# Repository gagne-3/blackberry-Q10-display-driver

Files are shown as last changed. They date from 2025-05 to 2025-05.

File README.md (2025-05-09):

# BlackBerry Q10 Display Assembly Driver

This repo contains the schematics and code for a display driver meant to provide compatibility with the BlackBerry Q10 display and touch screen.
> [!CAUTION]
> Heavy work in progress, project is to be considered non-functional and incomplete.

## Background Information

This project intends to provide a way to use a Q10 display assembly with a Raspberry Pi 4, but can be adapted to work with any computer that supports MIPI DSI.

The specific panel included in the Q10 display assembly, AMS309PW01, was specially made for the BlackBerry Q10 by Samsung SMD.  This display is a 3.1" AMOLED display with a resolution of 720x720. It communicates to the device using MIPI. Touch inputs are handled by an [Atmel mXT224S](https://www.microchip.com/en-us/product/atmxt224s#Documentation) connected to the built in digitizer.

## The Story

Initially, I fell down a rabbit hole and ended up looking into the wrong panel for this project. If you search for 3.1" 720x720 displays, the only readily available one is the LT031MDZ4000. These panels can be found readily on Aliexpress and Alibaba with MIPI driver boards. Others have also worked on creating custom drivers for this panel, notably [Jamwu](https://github.com/jamwu/RPI-LCD-LT031MDZ4000) and [Will-TM](https://github.com/will-tm/RPI-LCD-LT031MDZ4000).

Unfortunately, once I got my hands on a Q10 display module, I realized that it does not have a LT031MDZ4000 panel. Despite being the same size and resolution, the LT031MDZ4000 is an LCD panel that was made for the BlackBerry Q5, not the Q10. Upon tearing apart my Q10 display, I found the real panel model, AMS309PW01. Unfortunately for me, the AMS309PW01 is practically impossible to find information about. Only very basic information can be found on places such as [Panelook](https://www.panelook.com/AMS309PW01-0_Samsung_3.1_OLED_overview_21542.html). There do not appear to be any resellers of this panel, and there are no schematics or notes about how these panels work.

This caused me to lose hope on this project. Without a schematic, it was nearly impossible to create a driver board to make this display functional. I was considering going in with a multimeter and painstakingly reverse engineering the electronics attached to the display assembly. Thankfully, I caught a lucky break. While searching for schematics, I decided to search for general BlackBerry Q10 Schematics. That's when I fell upon a random blog that had a bunch of PDFs uploaded to it. These PDFs contained schematics for the entire mainboard of the Q10, which was exactly what I needed.

I will not link to the blog in question since it appeared to be a reupload. The PDFs are watermarked with a URL to what seems to be a dead website. a copy of the schematic can be found [here](schematics/sch-44860-106_rev1.pdf).

# Technical Details

## Q10 Display Connector Pinout

The display connector on the Q10 display assembly is a `Hirose BM14B(0.8)-30DP-0.4V`, which means that the driver board requires a `Hirose BM14B(0.8)-30DS-0.4V` socket to connect.

Below is a pinout of the Q10 motherboard display connector socket compiled from information present on Page 28 of the schematic.

| Pin | Signal Name | Description |
| --- | --- | --- |
| MP1 | GND | Ground |
| MP2 | GND | Ground |
| 1 | VSYS_F | Main system power |
| 2 | V2_85TSP_F | Touchscreen AVDD (2.85V) |
| 3 | VSYS_F | Main system power |
| 4 | V1_8TSP_F | Touchscreen VDD (1.8V) |
| 5 | GND | Ground |
| 6 | GND | Ground |
| 7 | — | Not Connected |
| 8 | I2C_SCL_TS | Touchscreen I²C Clock |
| 9 | GND | Ground |
| 10 | I2C_SDA_TS | Touchscreen I²C Data |
| 11 | OLED_MIPI:D1_P | MIPI DSI Data Lane 1+ |
| 12 | GND | Ground |
| 13 | OLED_MIPI:D1_N | MIPI DSI Data Lane 1− |
| 14 | TSCRN_INT_N | Touchscreen Interrupt |
| 15 | GND | Ground |
| 16 | TSCRN_RST_N | Touchscreen Reset |
| 17 | OLED_MIPI:CLK_P | MIPI DSI Clock+ |
| 18 | GND | Ground |
| 19 | OLED_MIPI:CLK_N | MIPI DSI Clock− |
| 20 | V3_10LED_F | Display power (3.1V) |
| 21 | GND | Ground |
| 22 | V3_10LED_F | Display power (3.1V) |
| 23 | OLED_MIPI:D0_P | MIPI DSI Data Lane 0+ |
| 24 | GND | Ground |
| 25 | OLED_MIPI:D0_N | MIPI DSI Data Lane 0− |
| 26 | V2_20LED_F | Display secondary power (2.2V) |
| 27 | GND | Ground |
| 28 | V2_20LED_F | Display secondary power (2.2V) |
| 29 | OLED_RST_N | Display Reset |
| 30 | GND | Ground |
| MP3 | GND | Ground |
| MP4 | GND | Ground |

Note: the pinout from Hirose is different to how the Blackberry schematic labels the pins. The official pinout from the manufacturer has the edge pins labeled as "MP#" while the Blackberry schematic includes them in the pin count. These edge pins are all grounds anyway, so I have included the official manufacturer pinout to match to the schematic.

## Raspberry Pi Display Connector Pinout

The display connector on the Raspberry Pi 4b is a 15 pin 1mm pitch FFC connector, specifically `SFW15R-2STE1LF`.

The following pinout of the Raspberry Pi 4b display connector is compiled from information from the [official Raspberry Pi 4b Schematic.](https://datasheets.raspberrypi.com/rpi4/raspberry-pi-4-reduced-schematics.pdf)

| Pin | Signal Name | Description |
| --- | --- | --- |
| 1 | GND | Ground |
| 2 | DSI1_DN1 | MIPI DSI Data Lane 1- |
| 3 | DSI1_DP1 | MIPI DSI Data Lane 1+ |
| 4 | GND | Ground |
| 5 | DSI1_CN | MIPI DSI Clock- |
| 6 | DSI1_CP | MIPI DSI Clock+ |
| 7 | GND | Ground |
| 8 | DSI1_DN0 | MIPI DSI Data Lane 0- |
| 9 | DSI1_DP0 | MIPI DSI Data Lane 0+ |
| 10 | GND | Ground |
| 11 | SCL0 | Touchscreen I²C Clock |
| 12 | SDA0 | Touchscreen I²C Data |
| 13 | GND | Ground |
| 14 | 3V3 | Display power (3.3V) |
| 15 | 3V3 | Display power (3.3V) |

## Display Panel Controller IC

Based on some basic googling and ChatGPT-ing, I believe the most likely controller IC for this panel is the Samsung S6E63M0. This IC is used in other Super AMOLED smartphone display panels of the time period and features the same integrated touchscreen architecture as is present on the Q10 display assembly.

Drivers for this controller IC already exist within the [Linux Kernel](https://github.com/torvalds/linux/blob/master/drivers/gpu/drm/panel/panel-samsung-s6e63m0-dsi.c)

## Power Supply Electronics

The Q10 display assembly requires four different voltages: 1.8, 2.2, 2.85, and 3.1 volts. The Raspberry Pi 4b display connector supplies 3.3 volts. We can provide these voltages by using LDO regulators. 1.8 volts is common for regulators, however adjustable regulators will be needed for the 2.2, 2.85, and 3.1 volt supplies. Below is a table detailing the necessary ICs for the driver board:

| Voltage | Part Number |
| --- | --- |
| 1.8v | TLV75718PDRVR |
| 2.2v | TLV75901PDRVR |
| 2.85v | TLV75901PDRVR |
| 3.1v | TLV75901PDRVR |

### Adjustable Voltage Resistance Values

In order to adjust the output voltage of the TLV759 LDOs, two resistors need to be connected, the ratio of which determines the output voltage. Below are the necessary resistance values for the LDOs:

| Voltage | R1 | R2 |
| --- | -- | -- |
| 2.2v | 30k | 10k |
| 2.85v | 38.3k | 9.09k |
| 3.1v | 42.2k | 9.09k |

## Logic Level Shifting

For the touchscreen reset and interrupt pins, we need to use a logic level shifter in order to be able to connect these to the GPIO of the raspberry pi. To do this, we can use a `TXB0102`.

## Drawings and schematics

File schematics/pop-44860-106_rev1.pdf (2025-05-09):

U3300

| REVISIONS

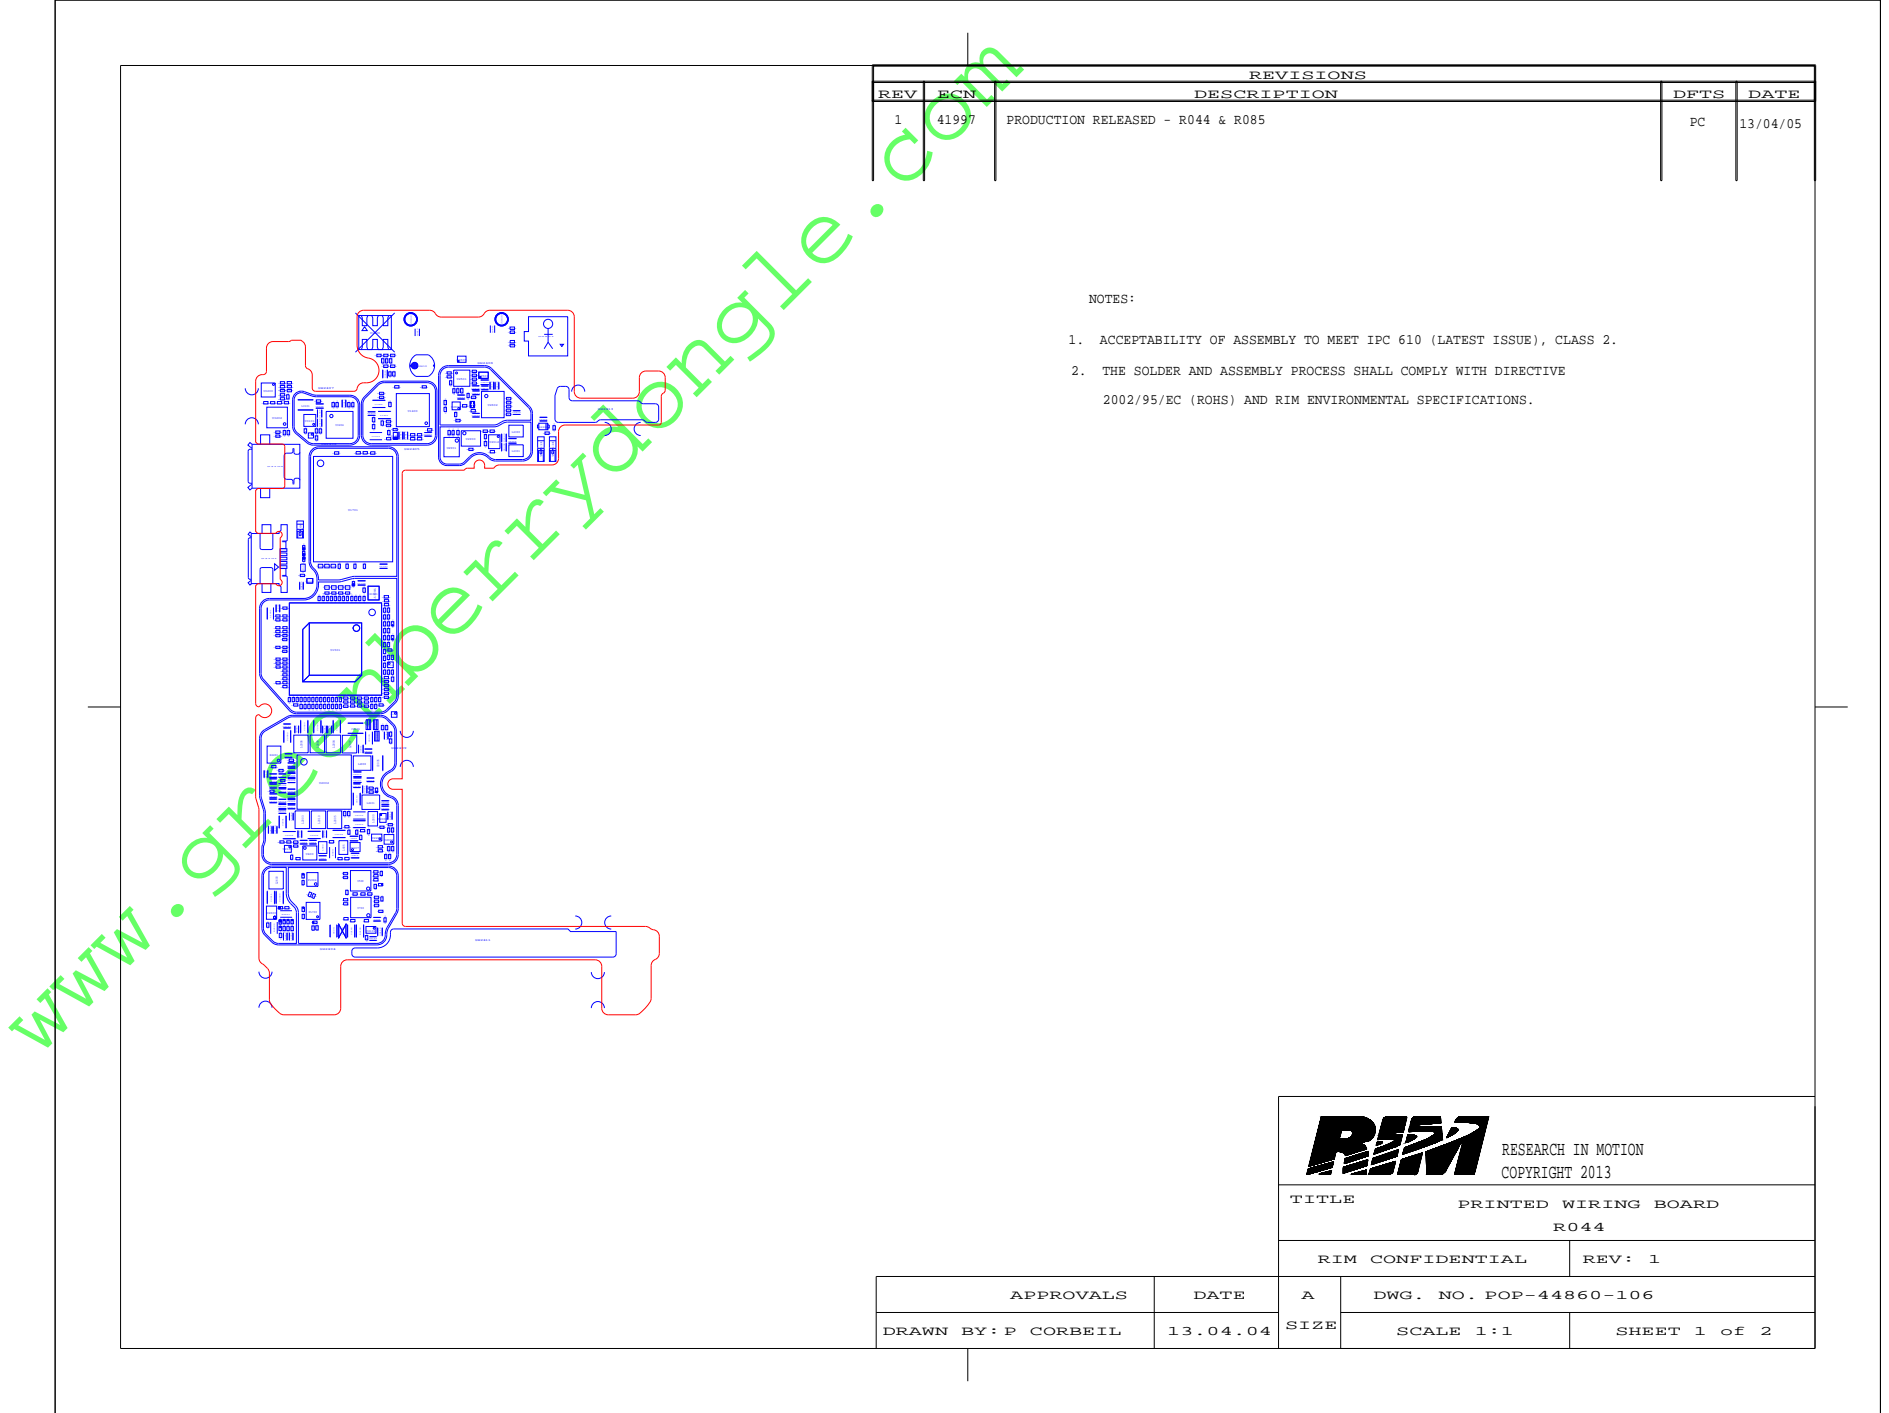
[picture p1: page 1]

REV | ECN | DESCRIPTION | DFTS | DATE

1. ACCEPTABILITY OF ASSEMBLY TO MEET IPC 610 (LATEST ISSUE), CLASS 2.

2. THE SOLDER AND ASSEMBLY PROCESS SHALL COMPLY WITH DIRECTIVE

2002/95/EC (ROHS) AND RIM ENVIRONMENTAL SPECIFICATIONS.

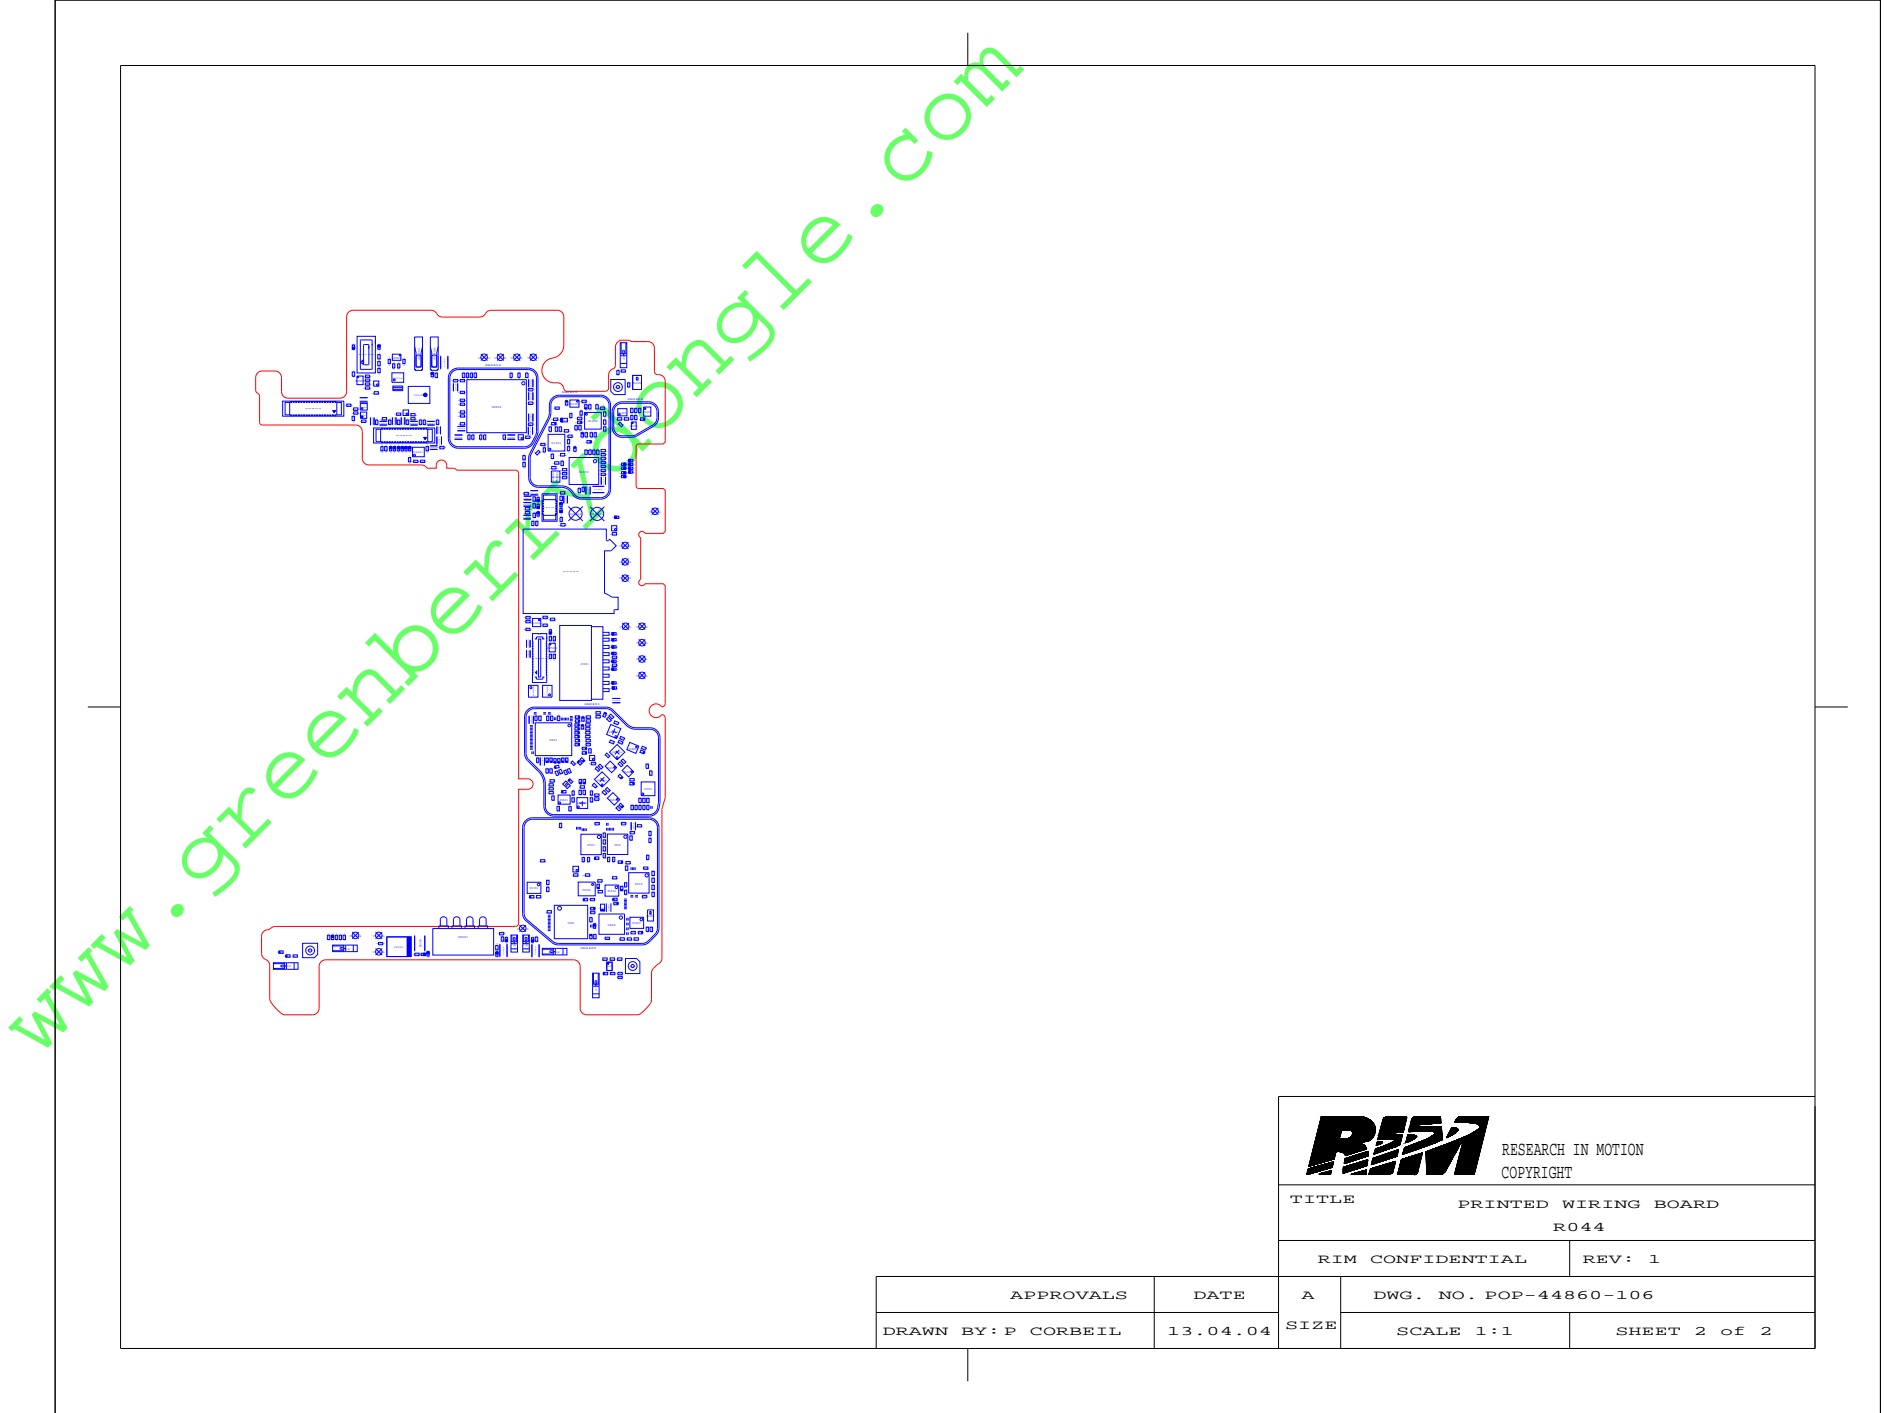
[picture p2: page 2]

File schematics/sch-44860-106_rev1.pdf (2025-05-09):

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

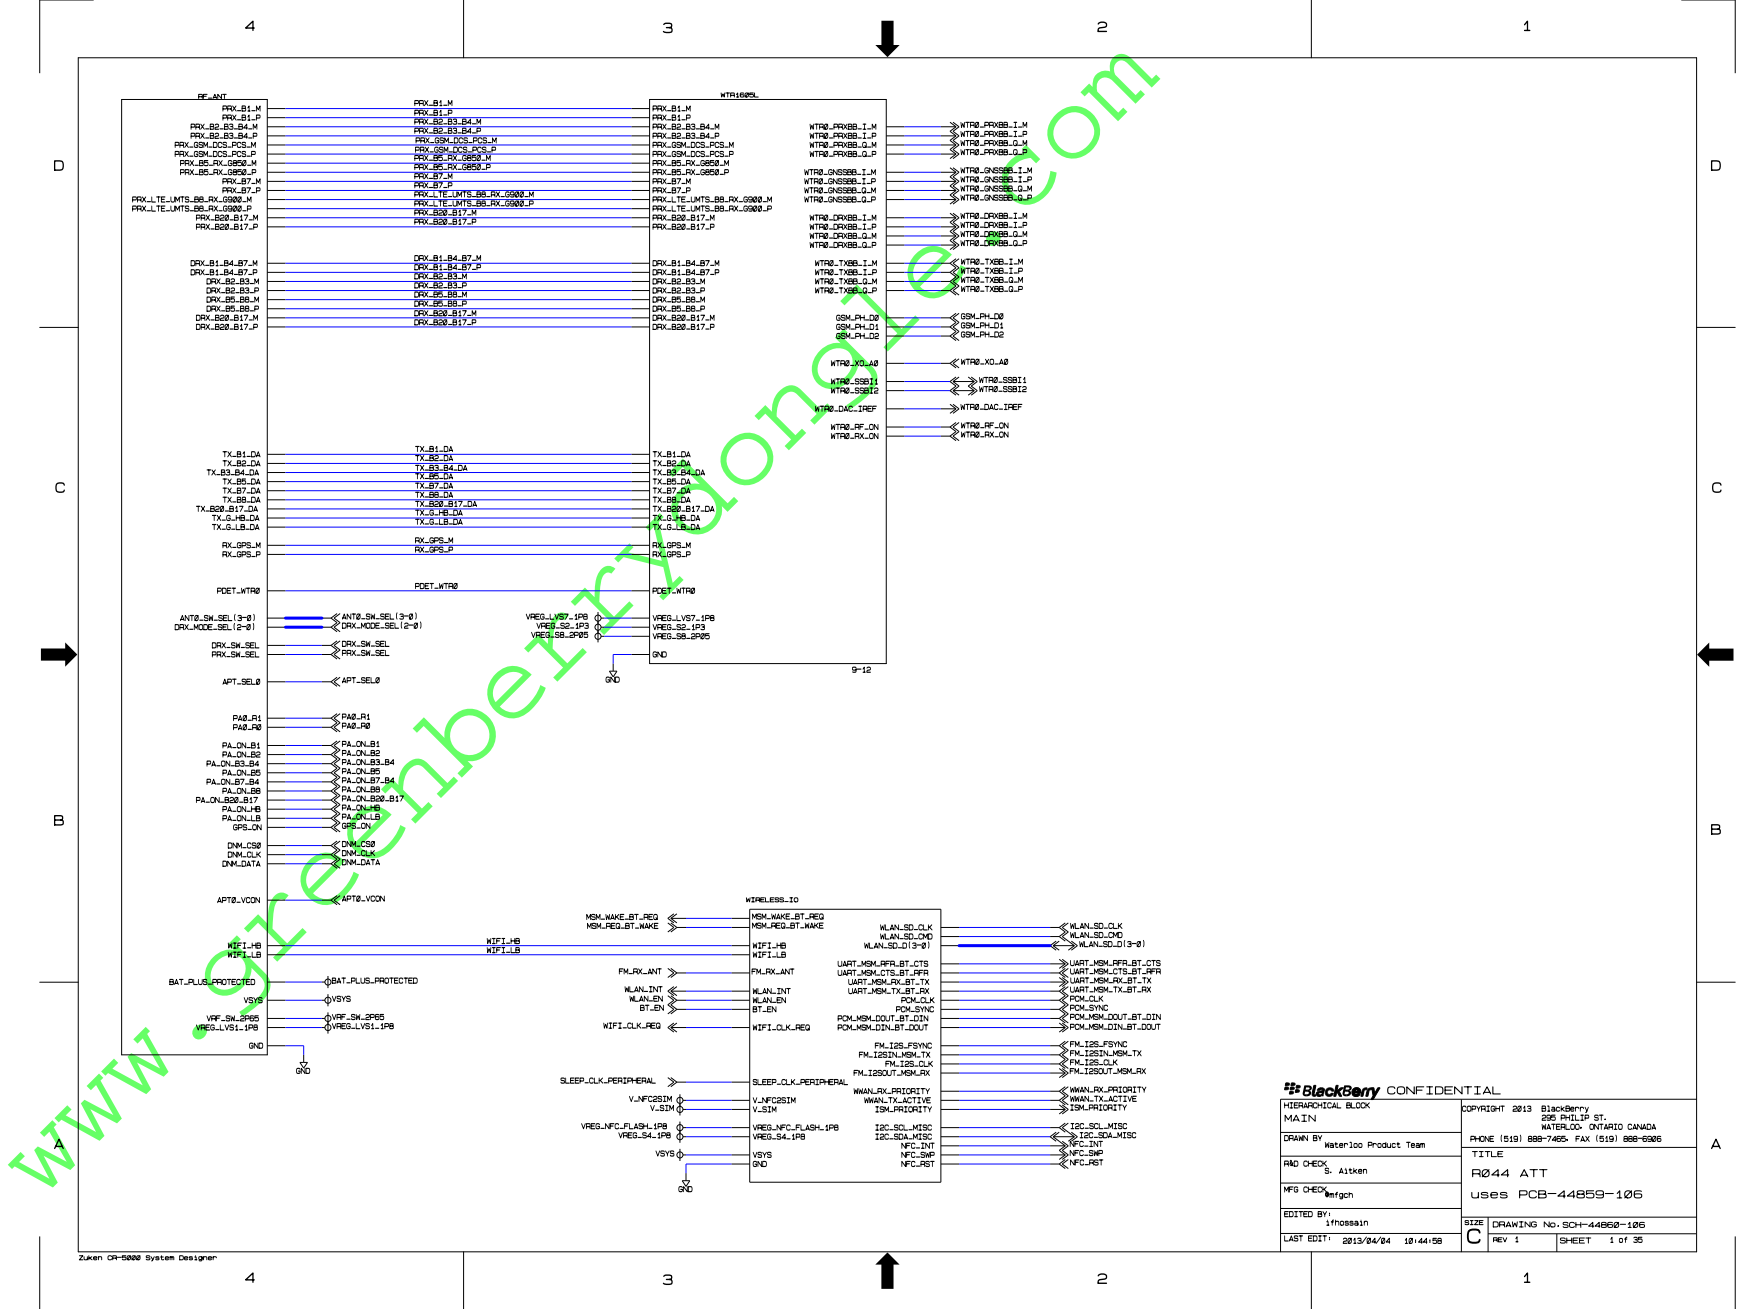
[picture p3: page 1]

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

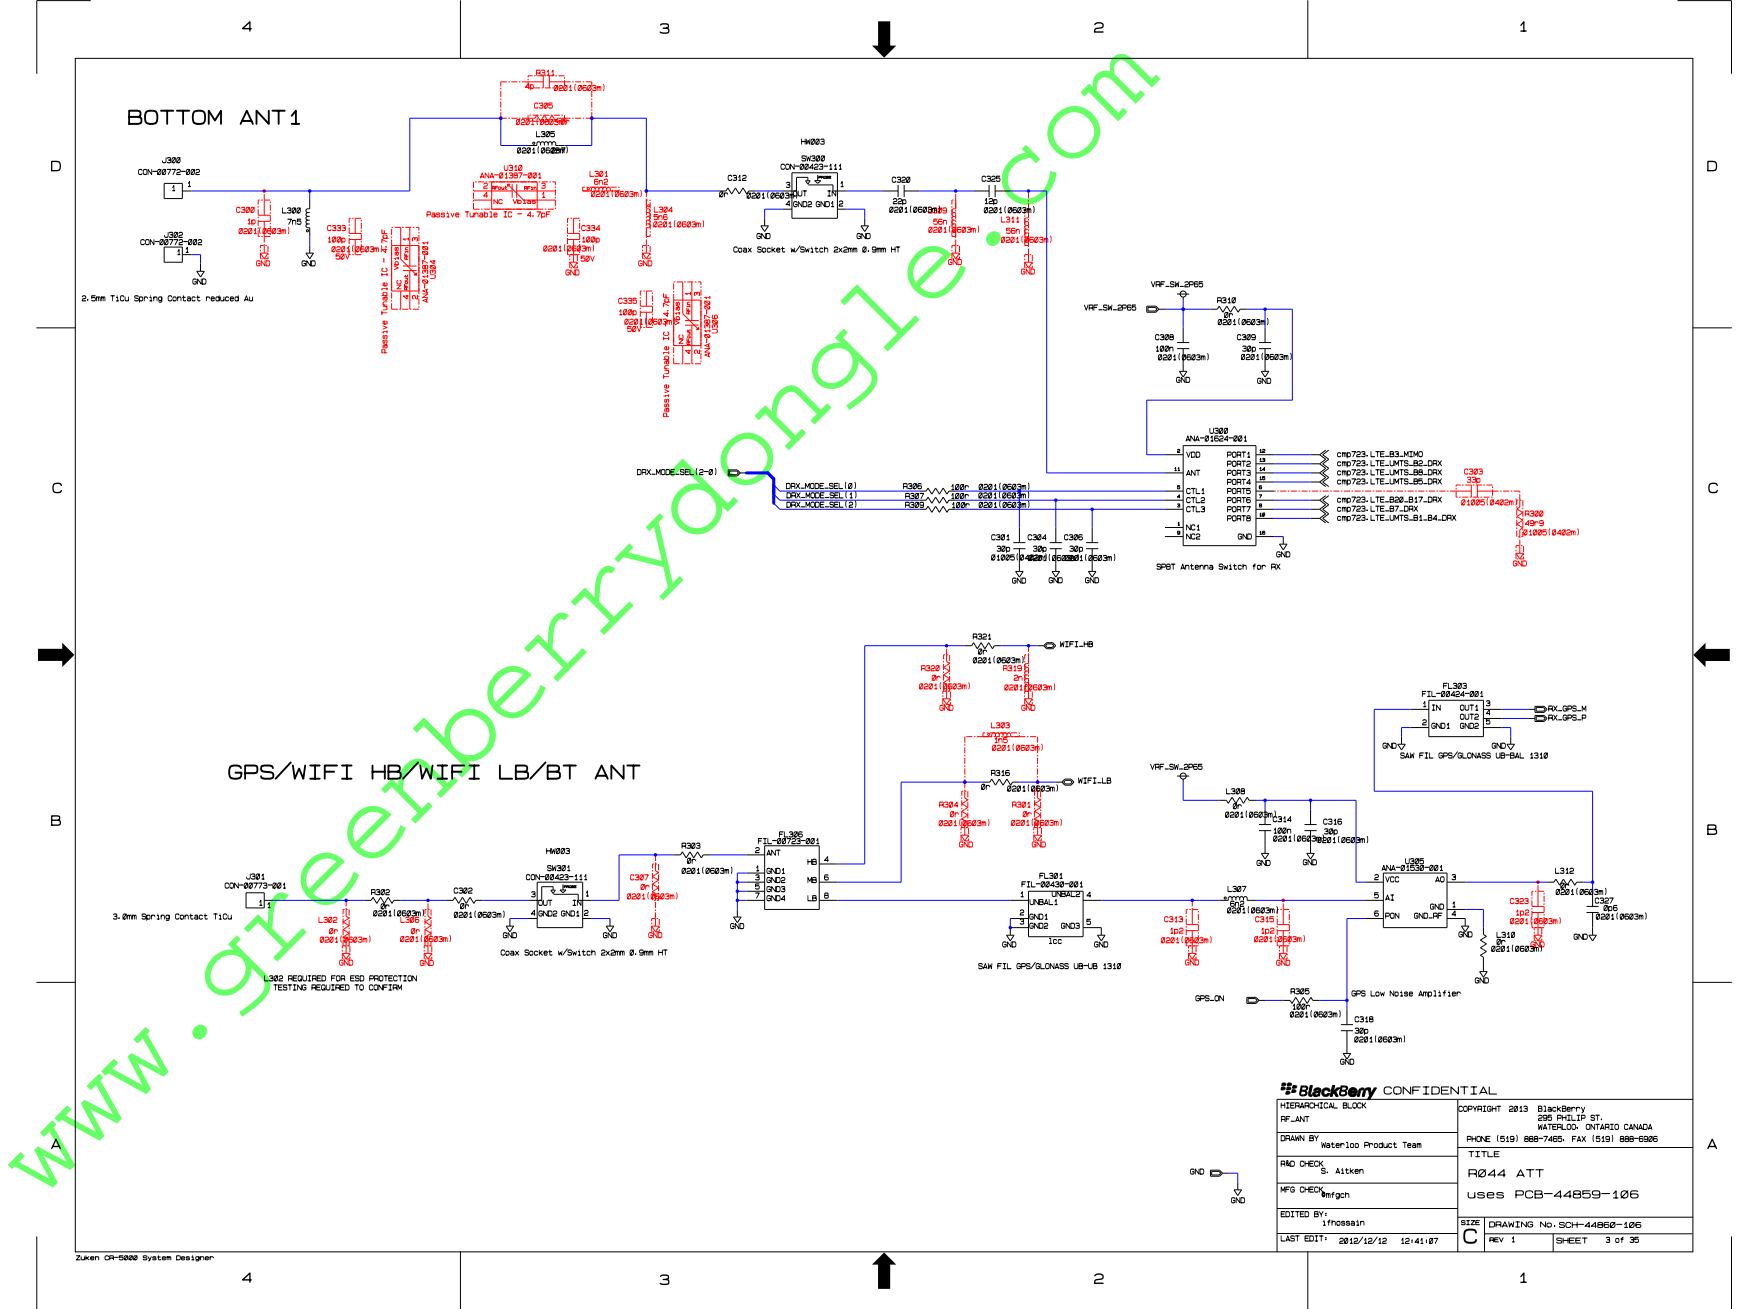
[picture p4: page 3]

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

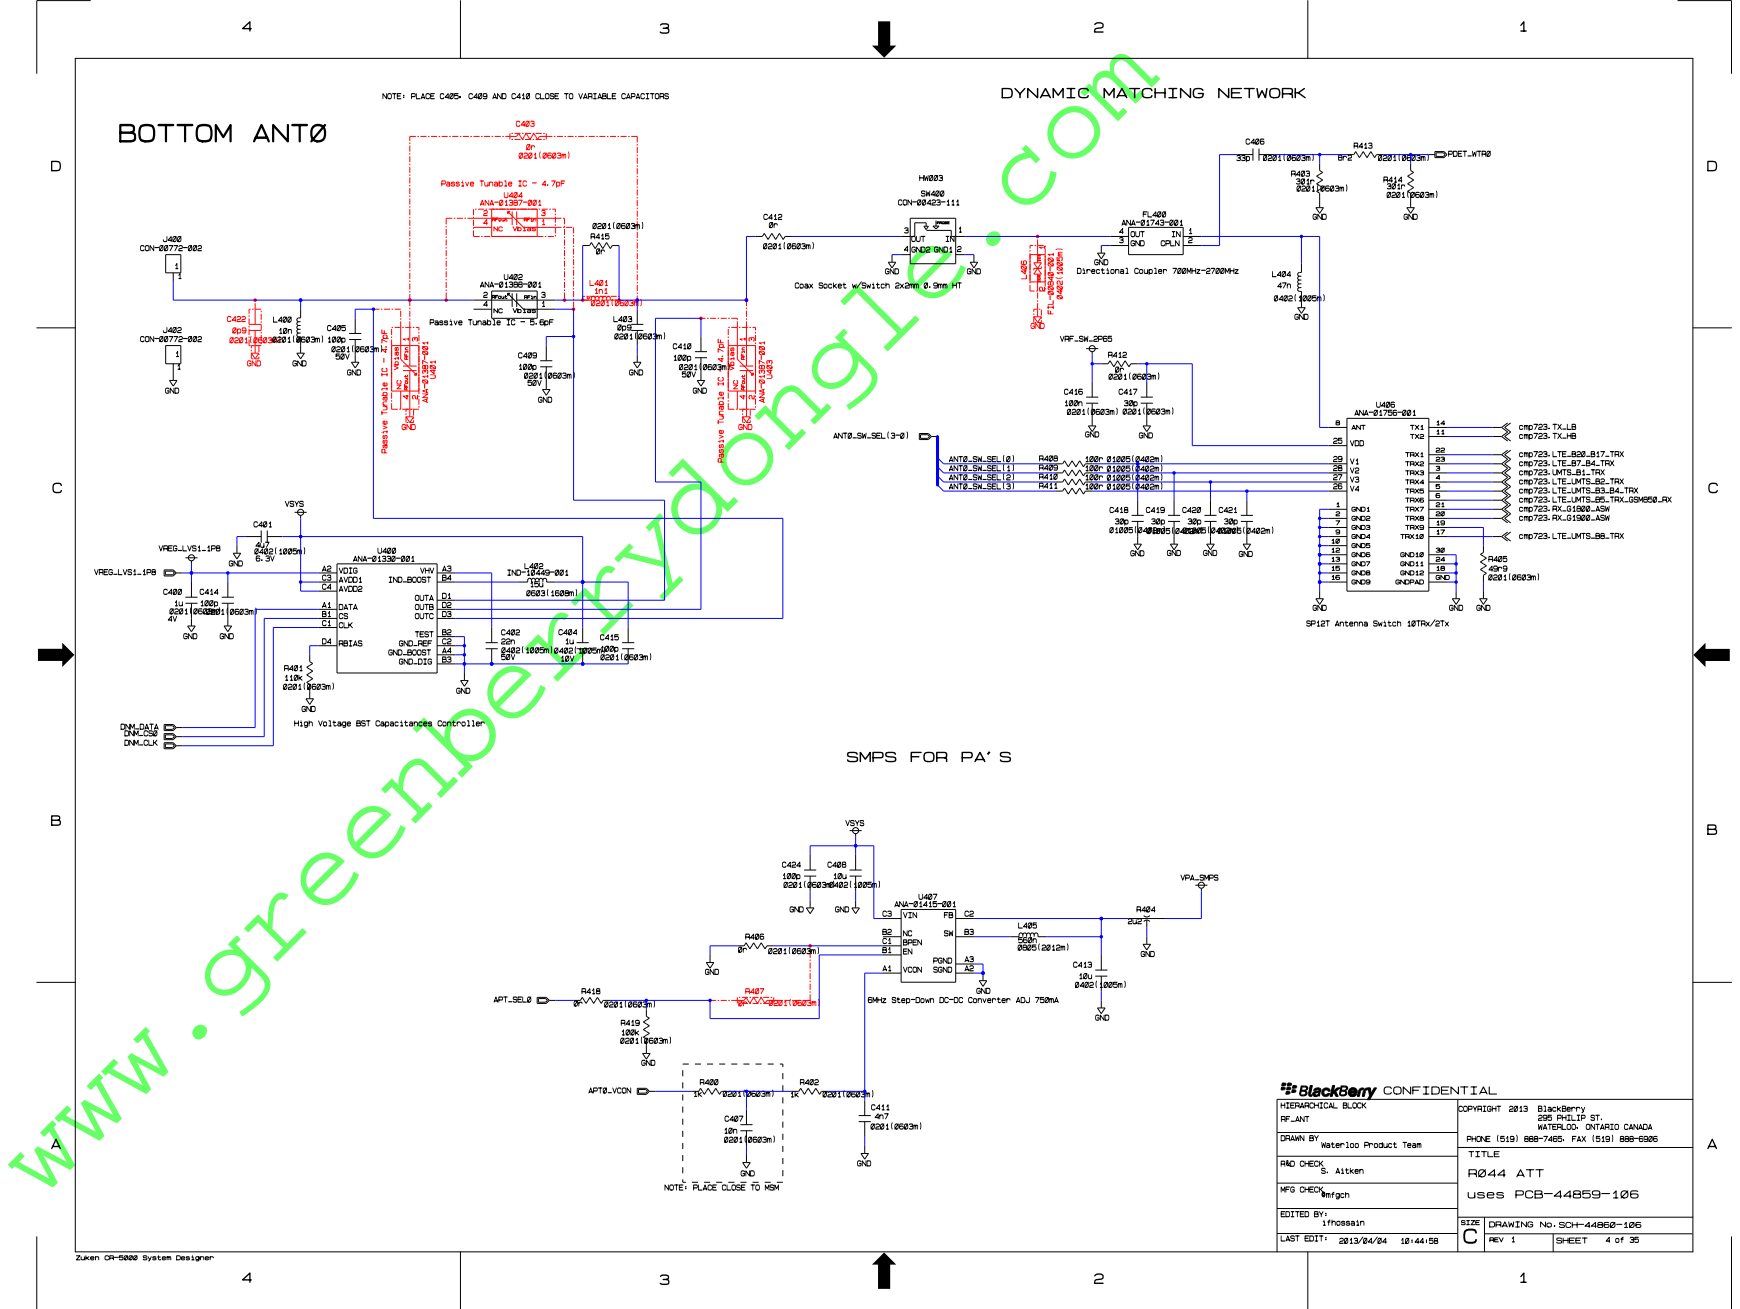
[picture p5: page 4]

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

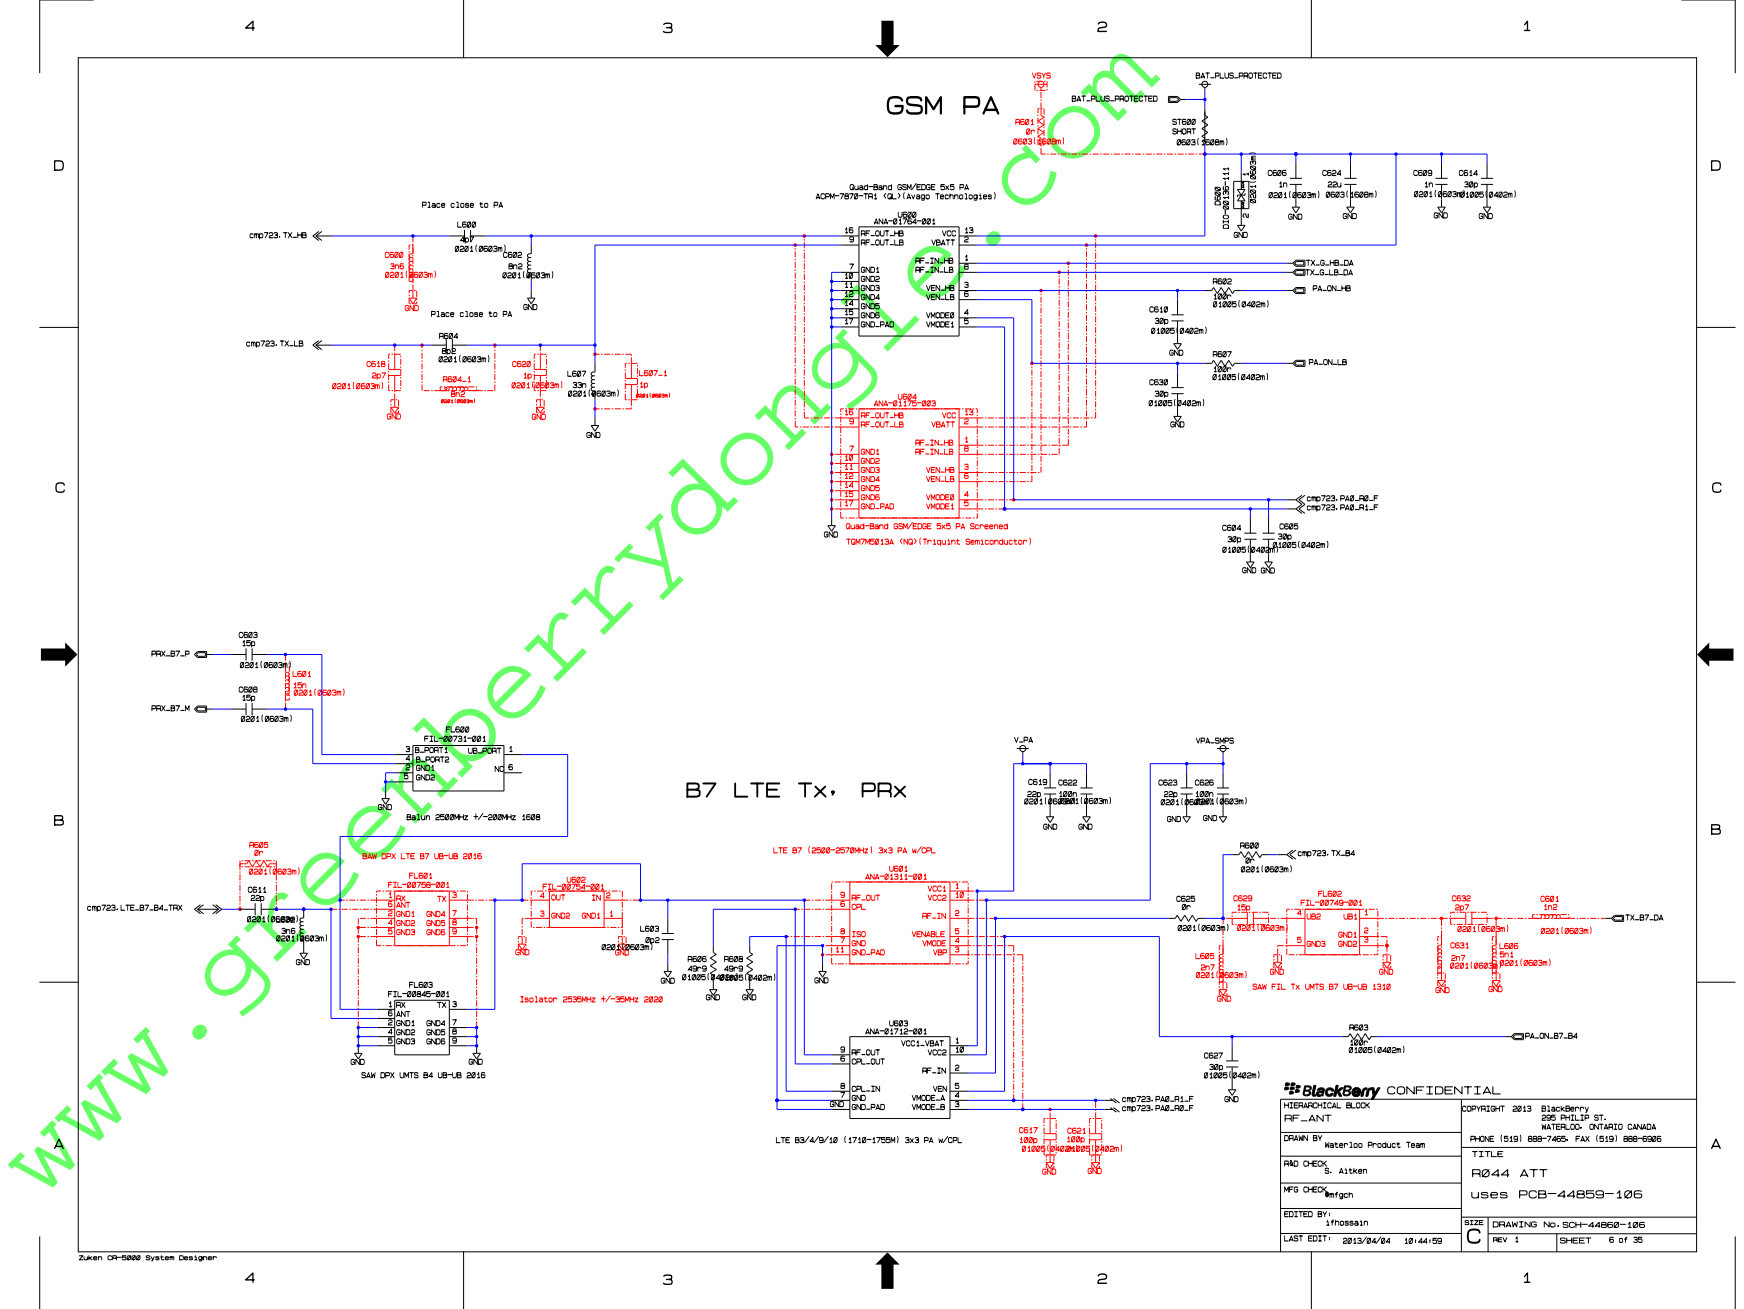
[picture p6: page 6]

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

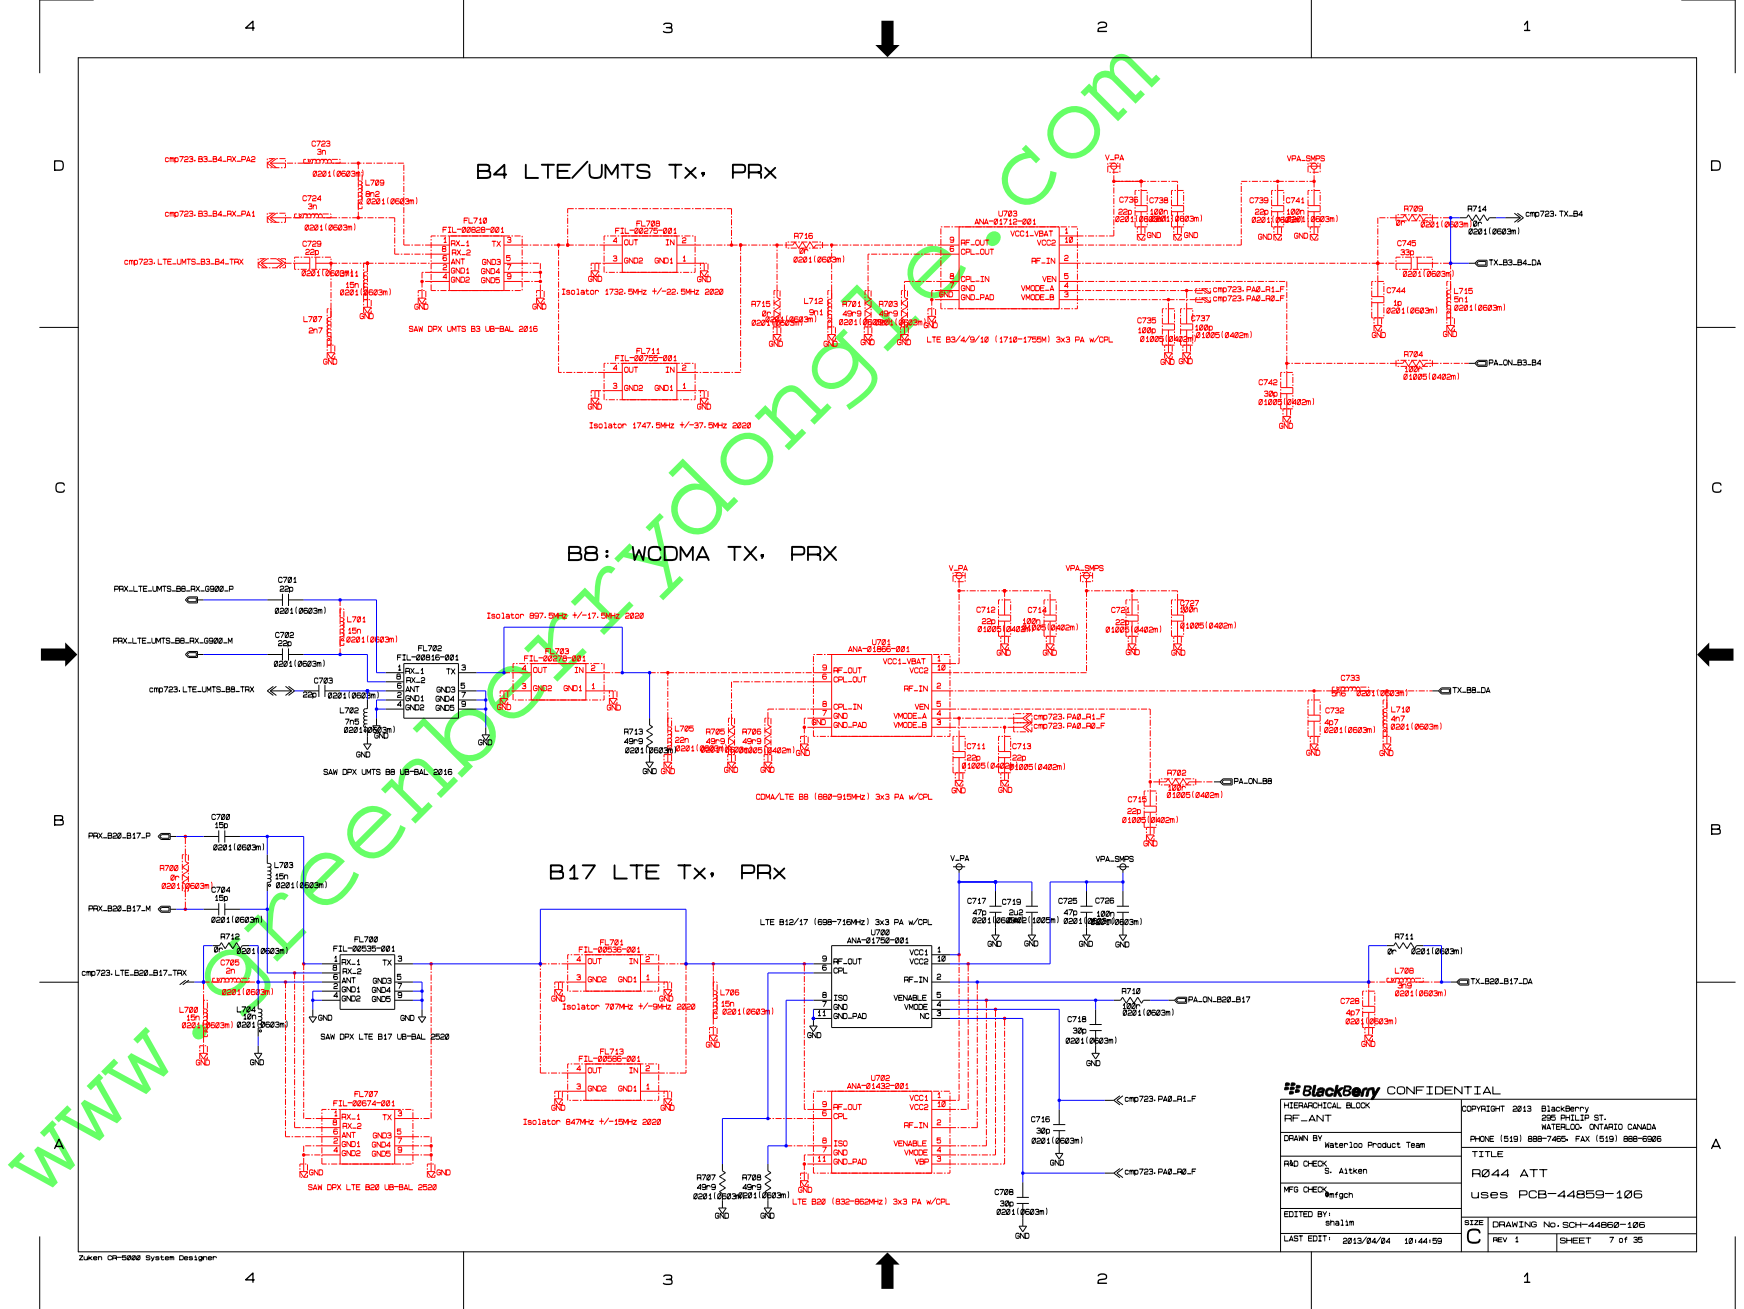
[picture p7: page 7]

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

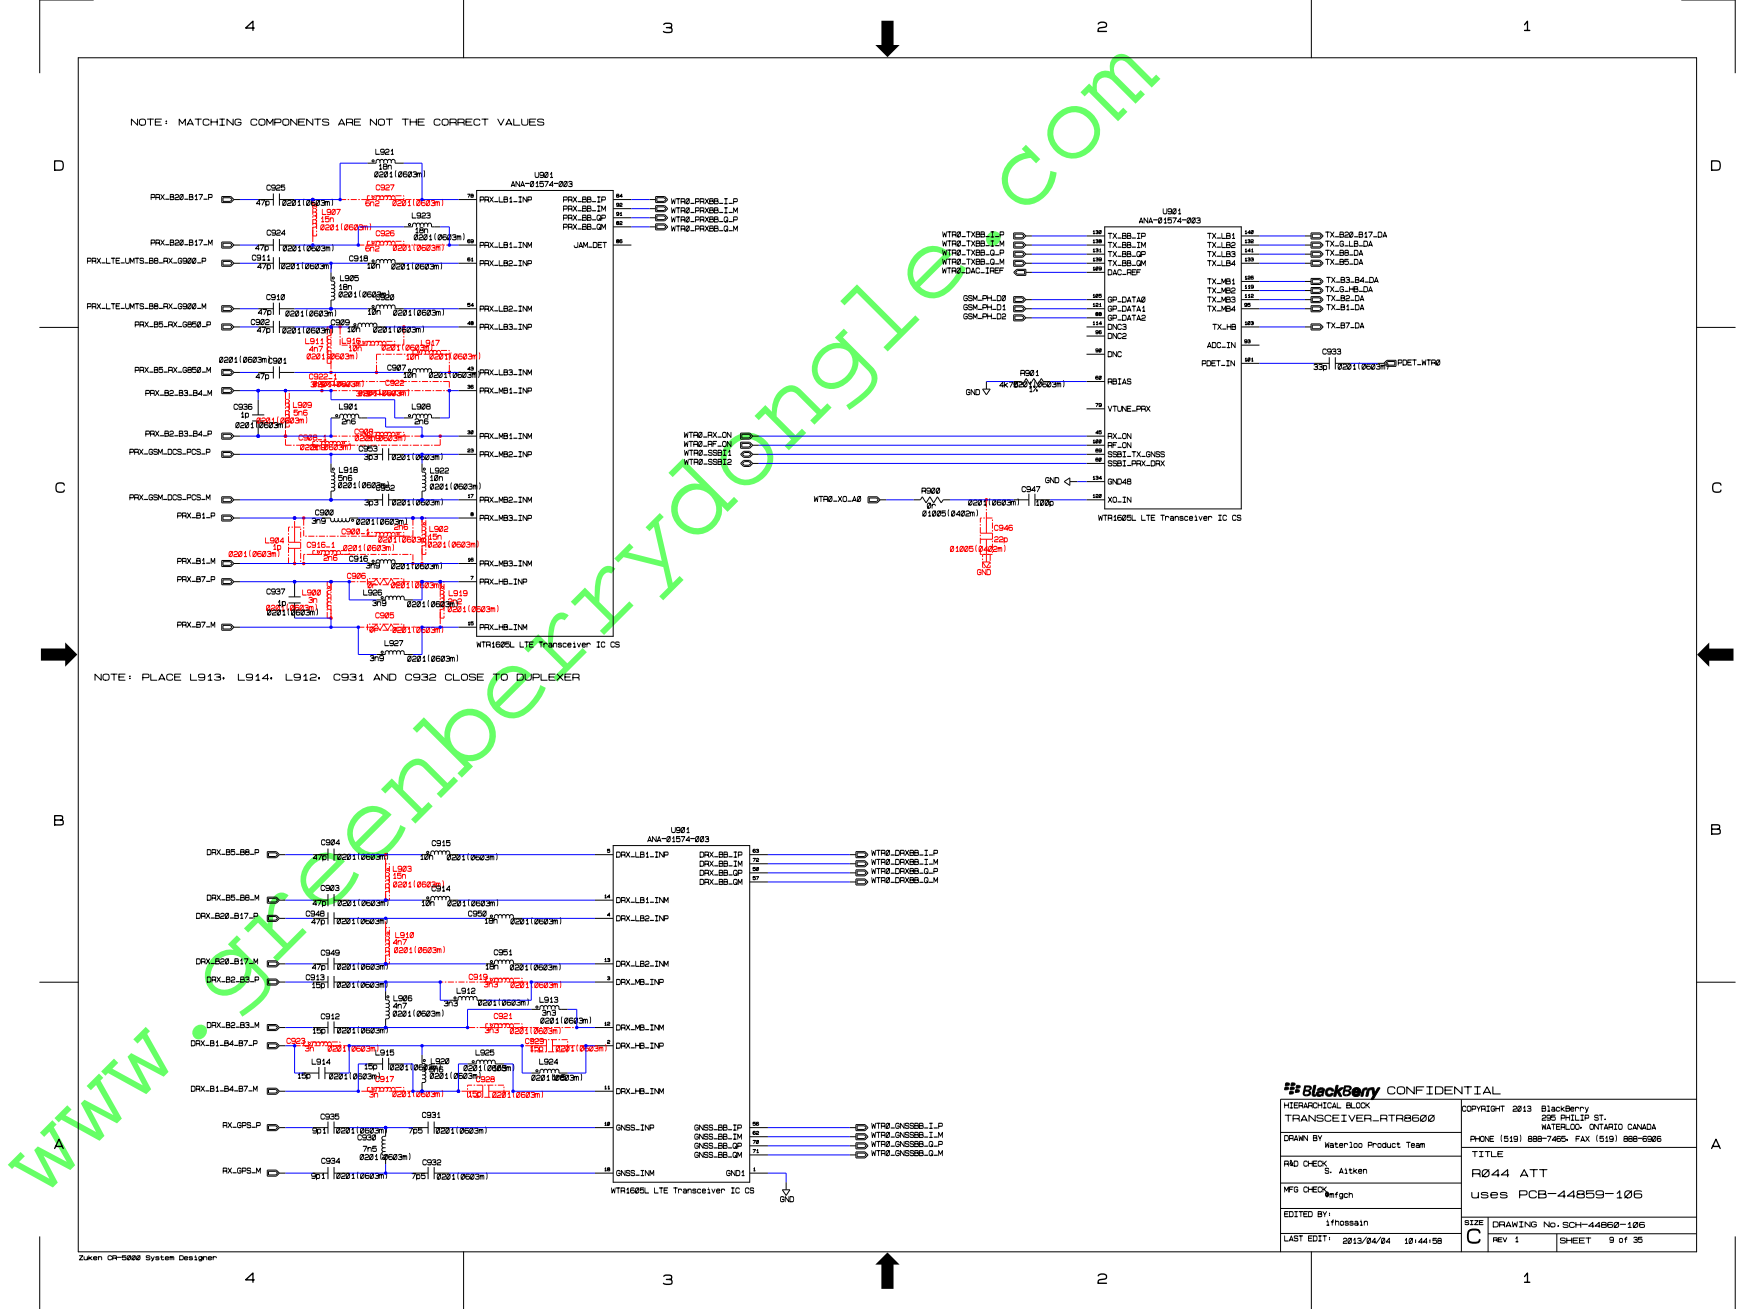
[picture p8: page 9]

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

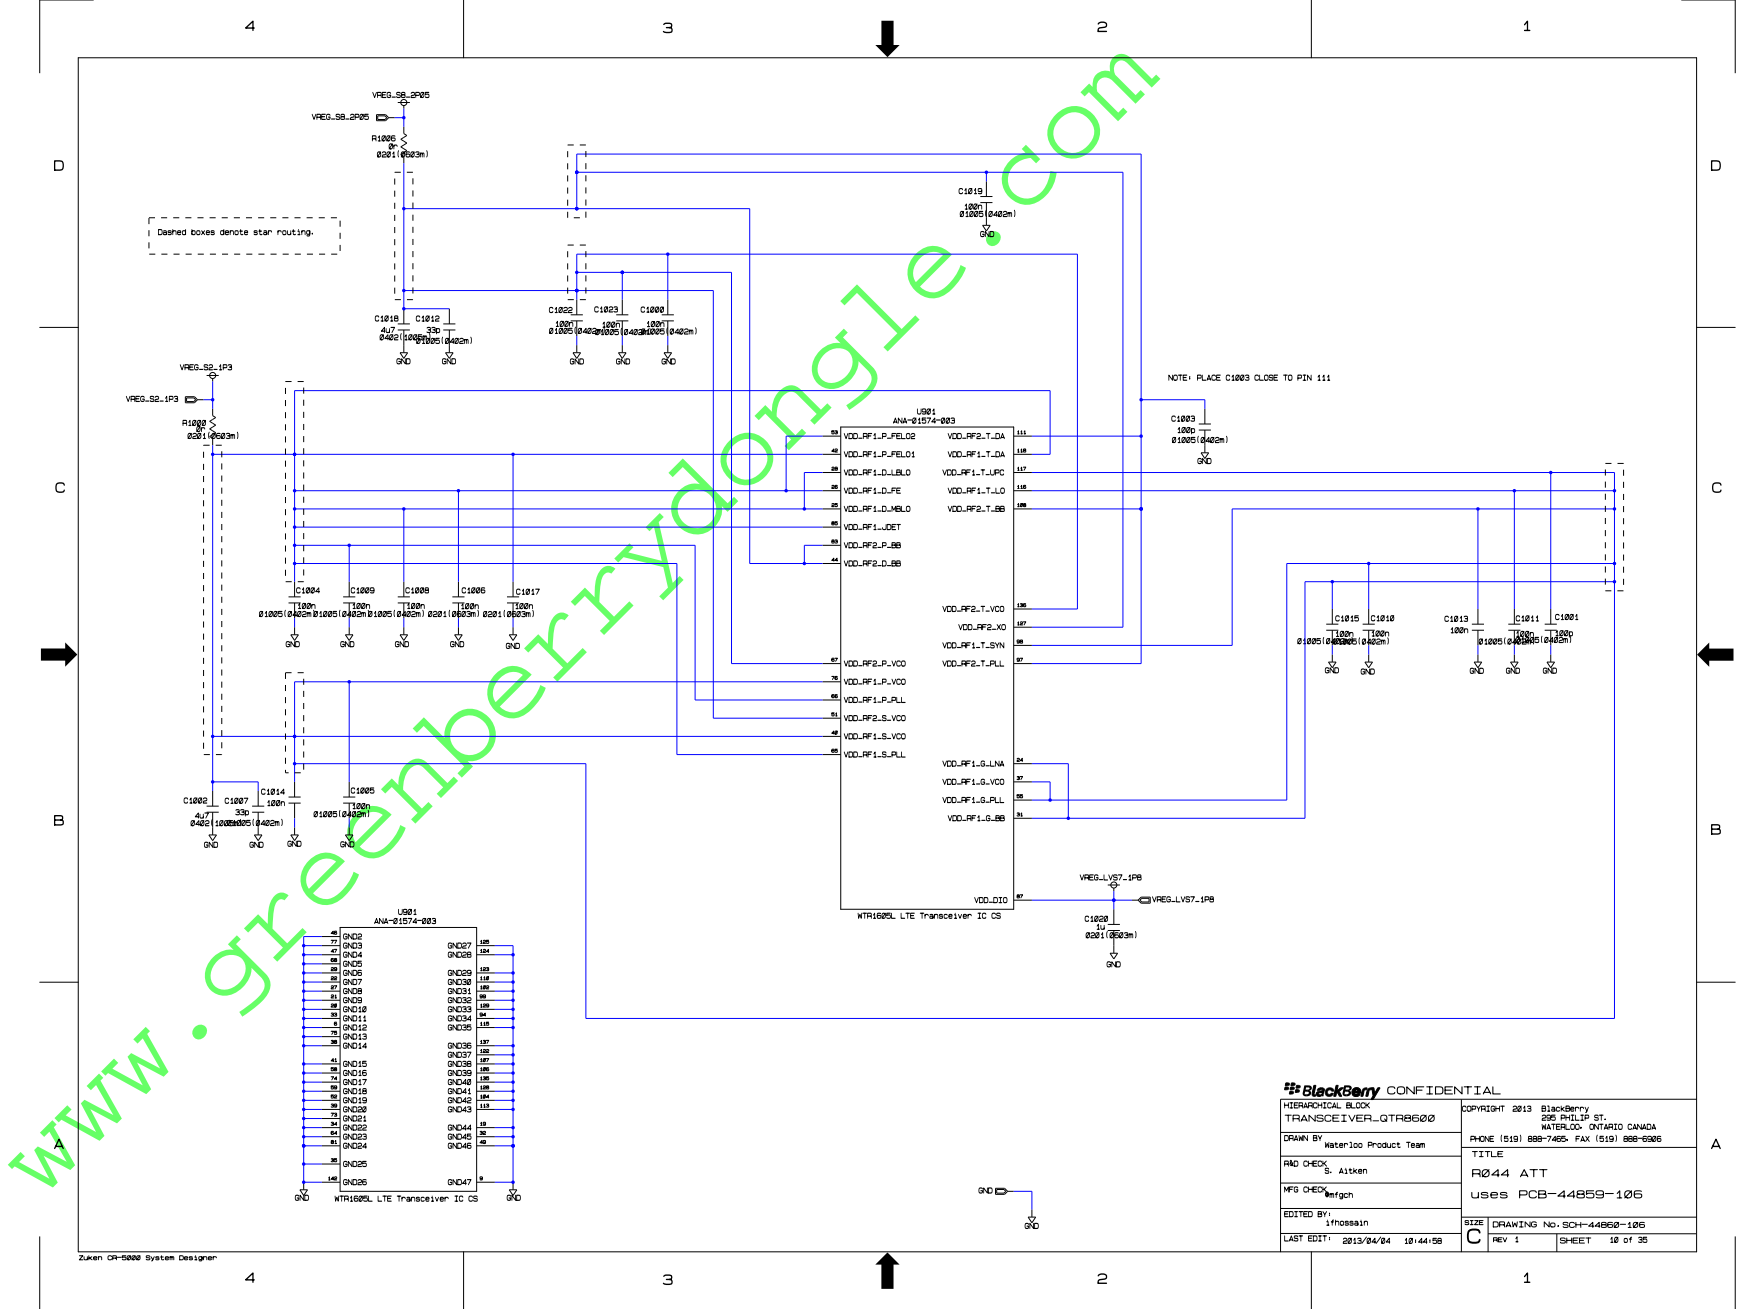
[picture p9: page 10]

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

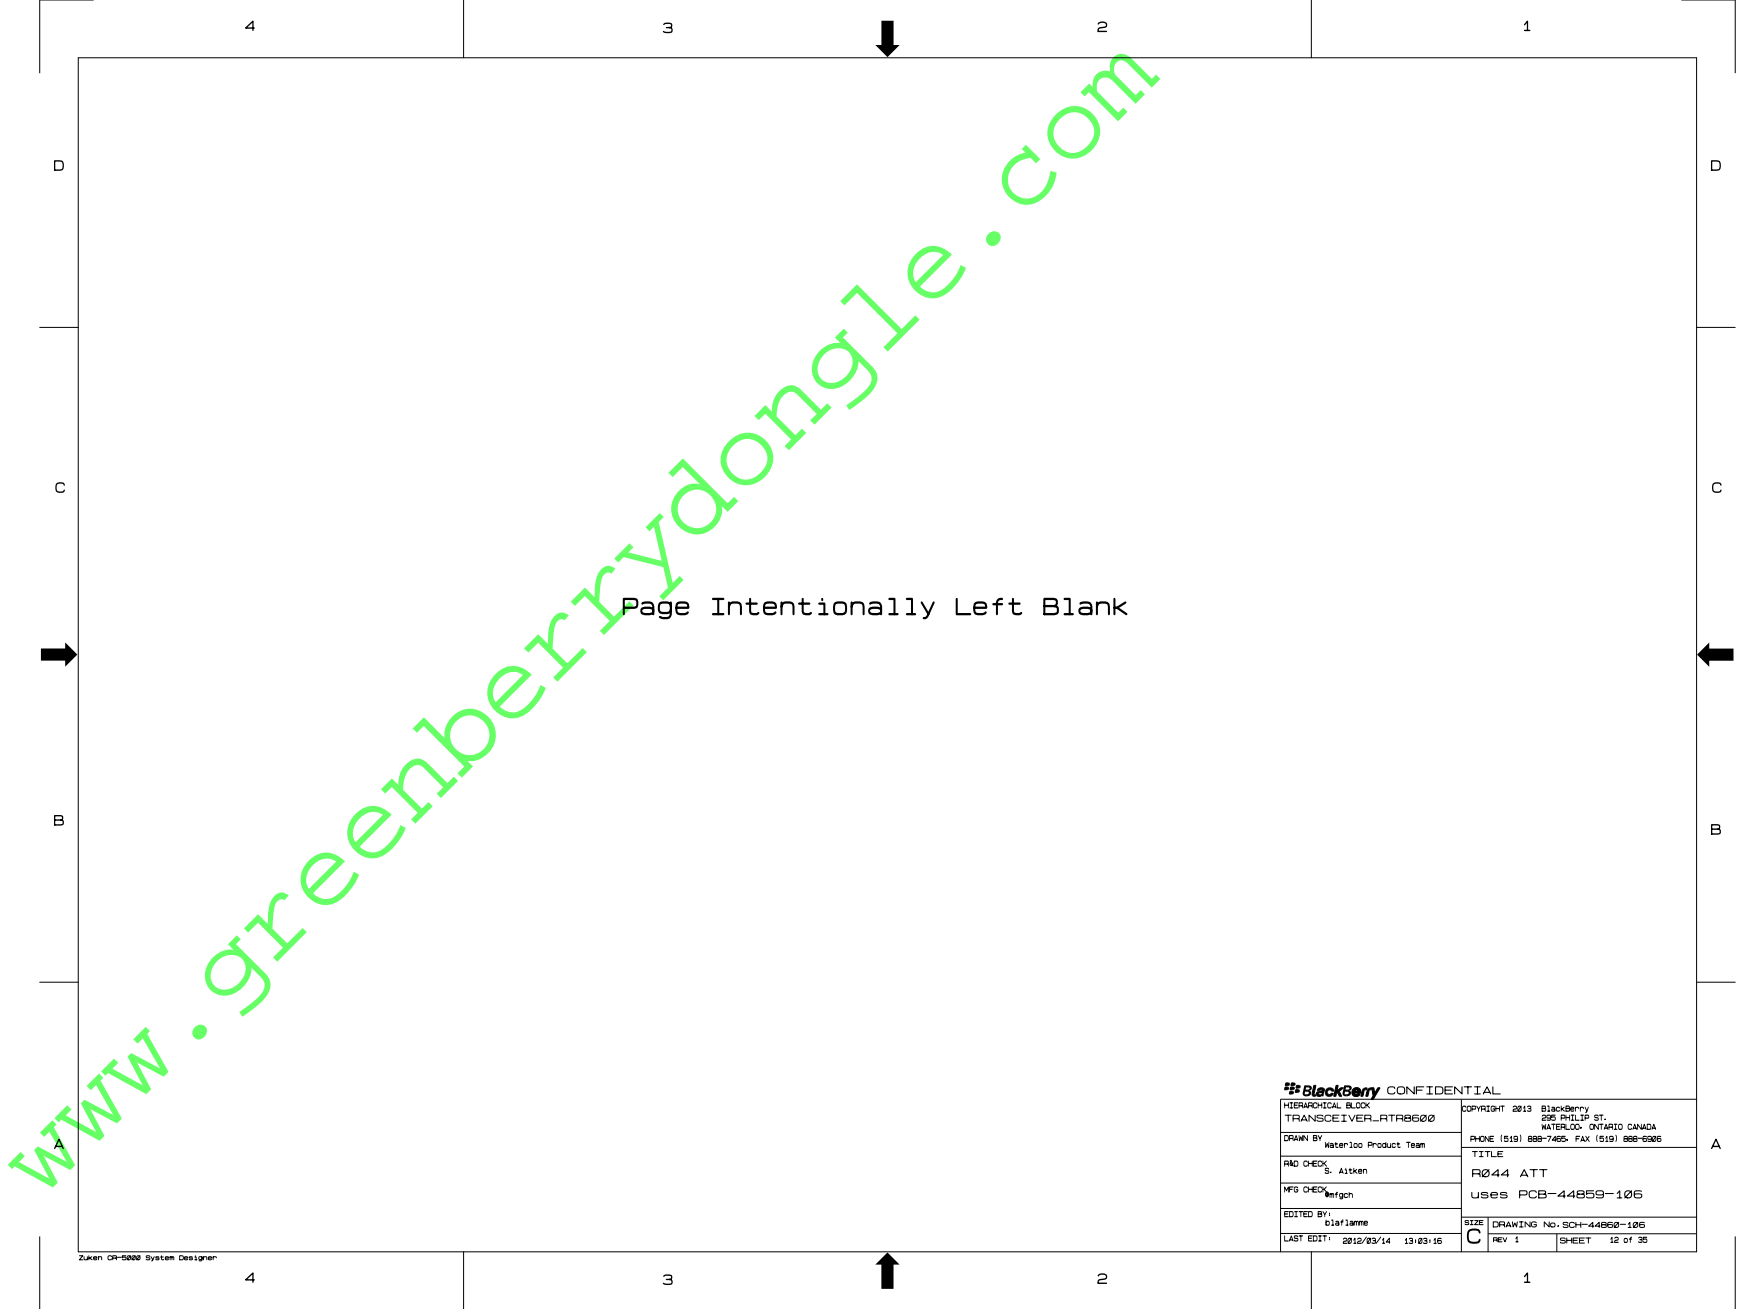
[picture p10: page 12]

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

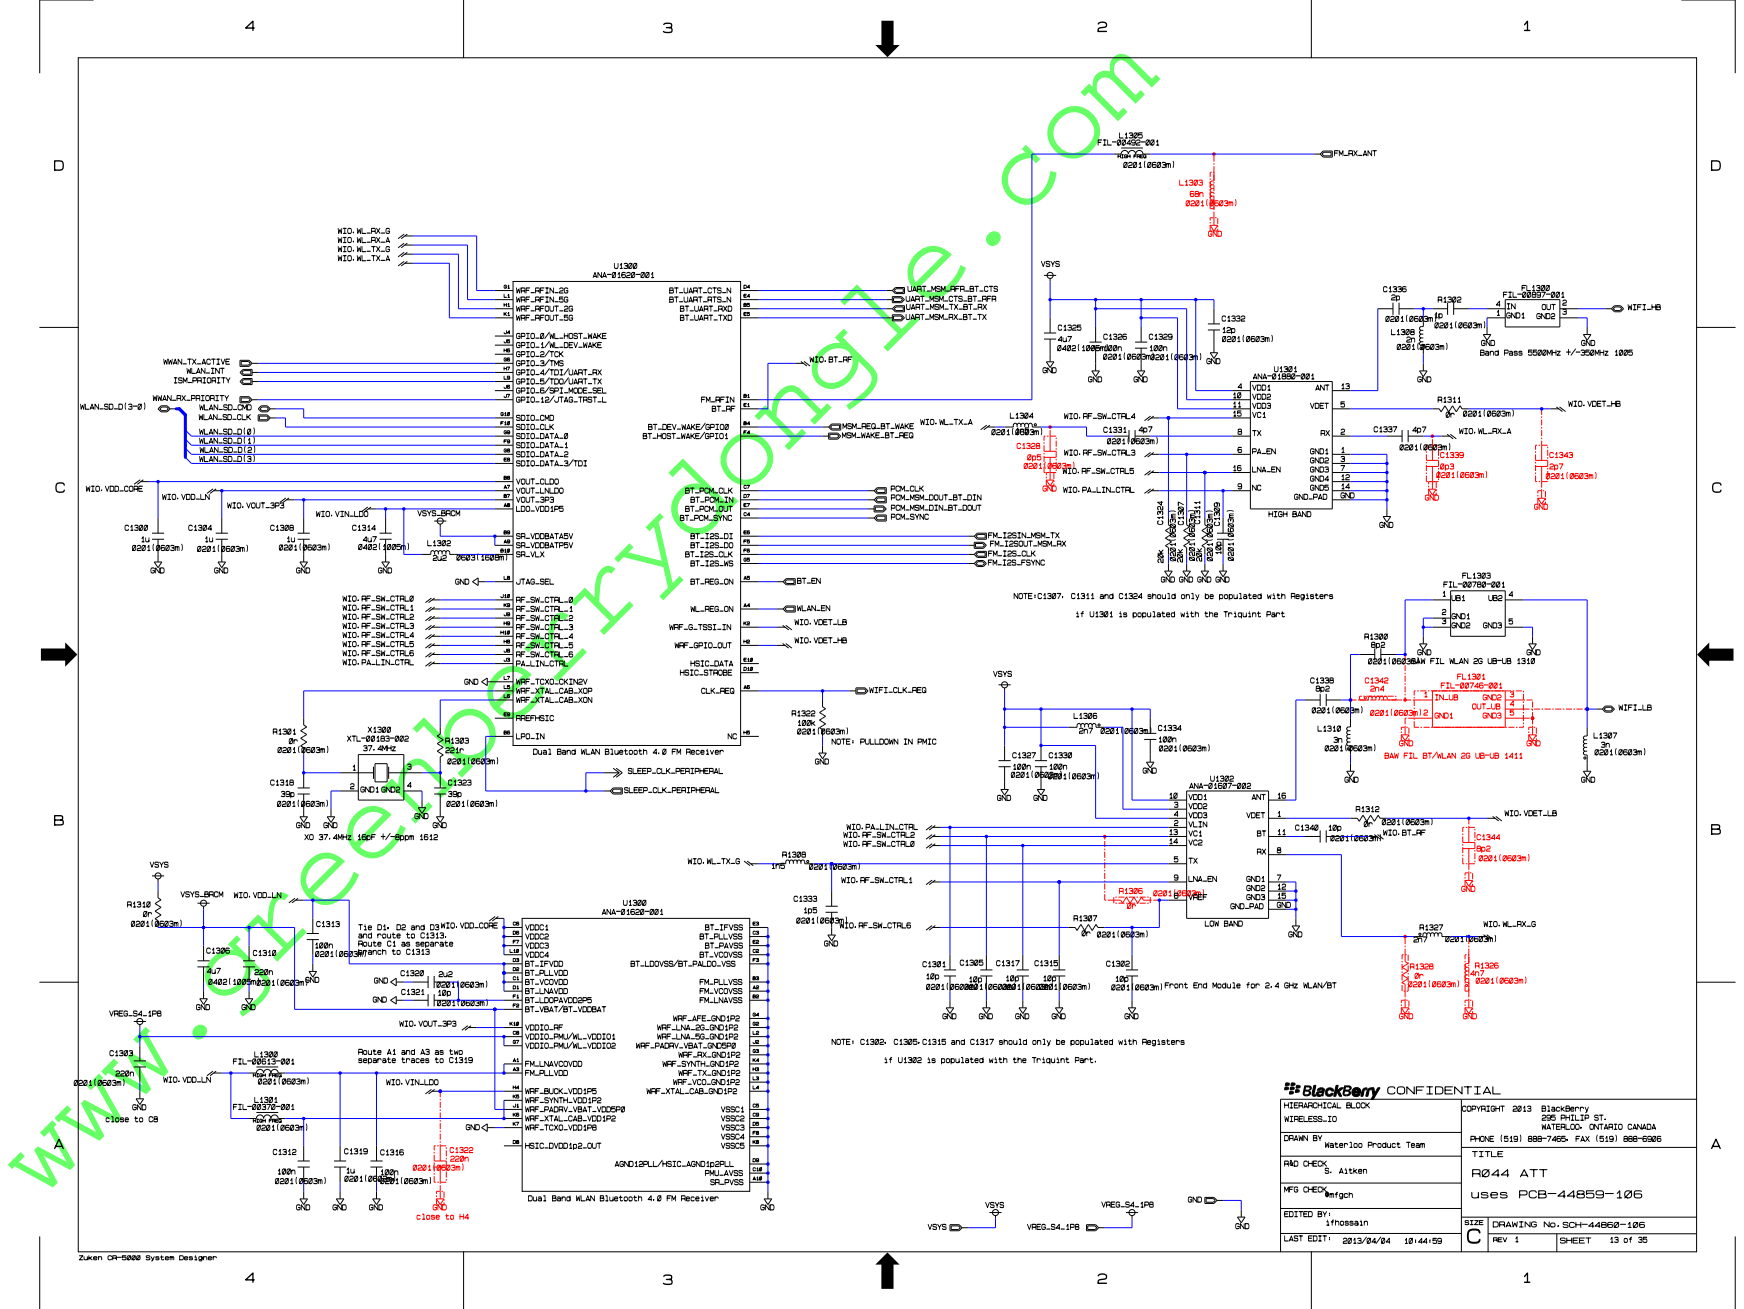
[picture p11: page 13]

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

4
1

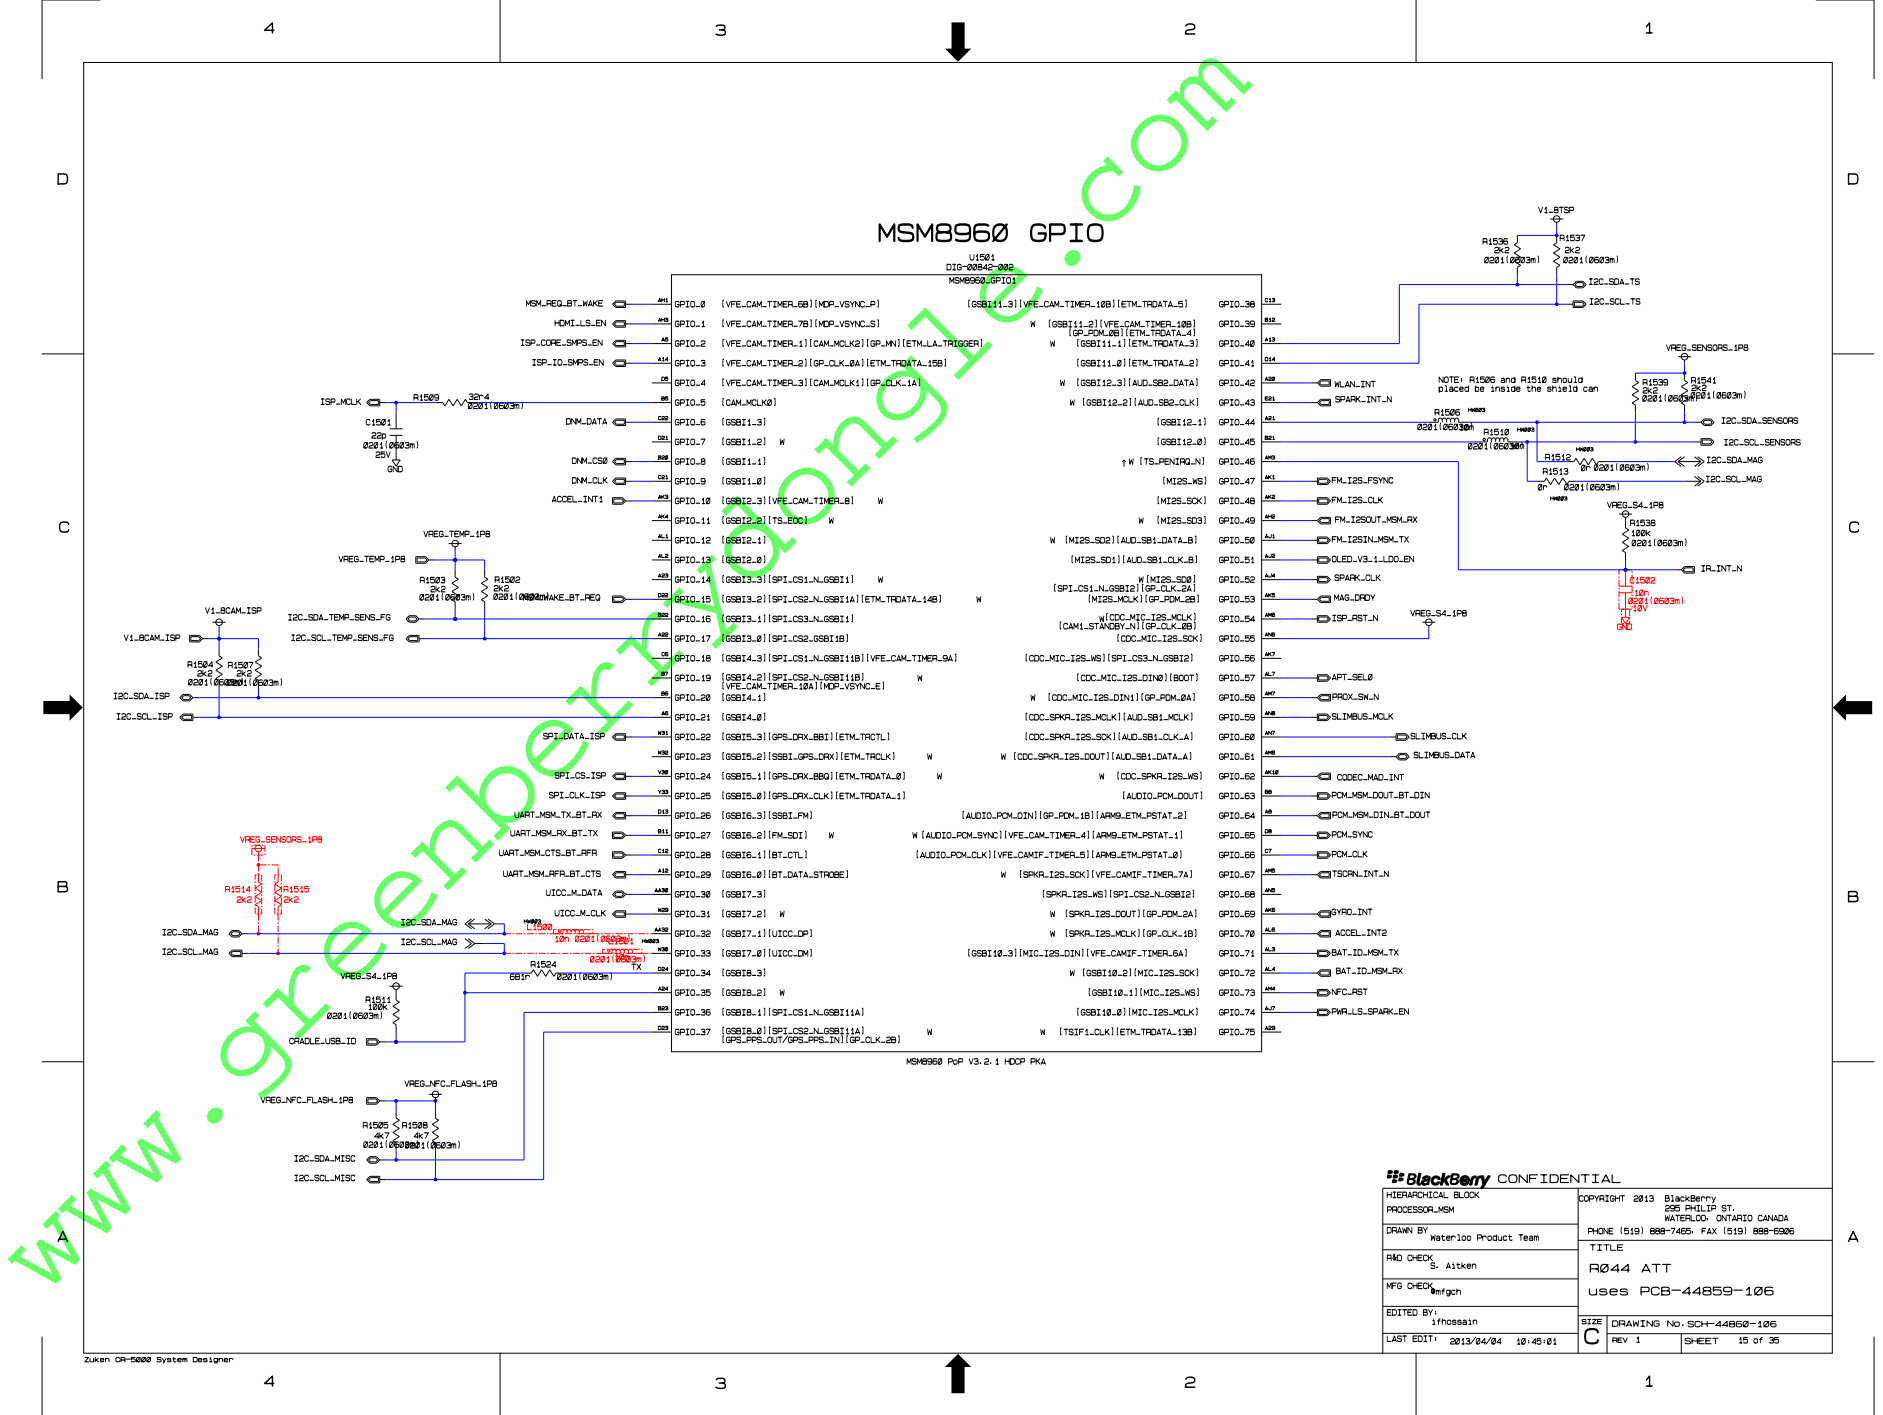
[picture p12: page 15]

NOTE: R1506 and R1510 should placed be inside the shield can

Zuken CR-5000 System Designer

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

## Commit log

2025-04-28 Updated readme with Q10 display connector info and RPI display connector pinout
2025-05-04 Created PCB and added display connector symbol
    [Q10-Driver-Board.kicad_pcb, Q10-Driver-Board.kicad_sch]
2025-05-04 Starting over because I don't know how to properly setup a KiCAD project
    [Q10-Driver-Board.kicad_pcb, Q10-Driver-Board.kicad_sch]
2025-05-04 New empty kicad project with gitignore to prevent saving a bunch of junk
    [display-driver-board-Q10.kicad_pcb, display-driver-board-Q10.kicad_sch]
